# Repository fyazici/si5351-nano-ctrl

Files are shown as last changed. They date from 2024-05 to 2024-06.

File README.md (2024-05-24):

si5351-nano-ctrl
==

This is a simple Arduino Nano project to control the commonly available SI5351 oscillator board (originally from Adafruit). 1.44" SPI TFT/OLED screen is used as the graphical interface. A rotary encoder and 4 buttons allow menu navigation and frequency adjustments.

Features include:
* Full range of frequencies from 2.5 kHz up to 300 MHz (with PLL overclock, performance guaranteed range limited to 225 MHz, see AN619).
* Automatic selection of PLL operation modes based on frequencies requested.
* Adjustable drive strength.
* Up to 6 presets can be saved to EEPROM. Loads `Preset 0` at startup.
* Xtal frequency correction, also stored on EEPROM.

Provided KiCad design is suitable for one-sided PCBs, e.g. made by toner transfer method at home. For two or more layers, PCB design can be optimized to reduce noise and unwanted coupling of SPI signals to the output.

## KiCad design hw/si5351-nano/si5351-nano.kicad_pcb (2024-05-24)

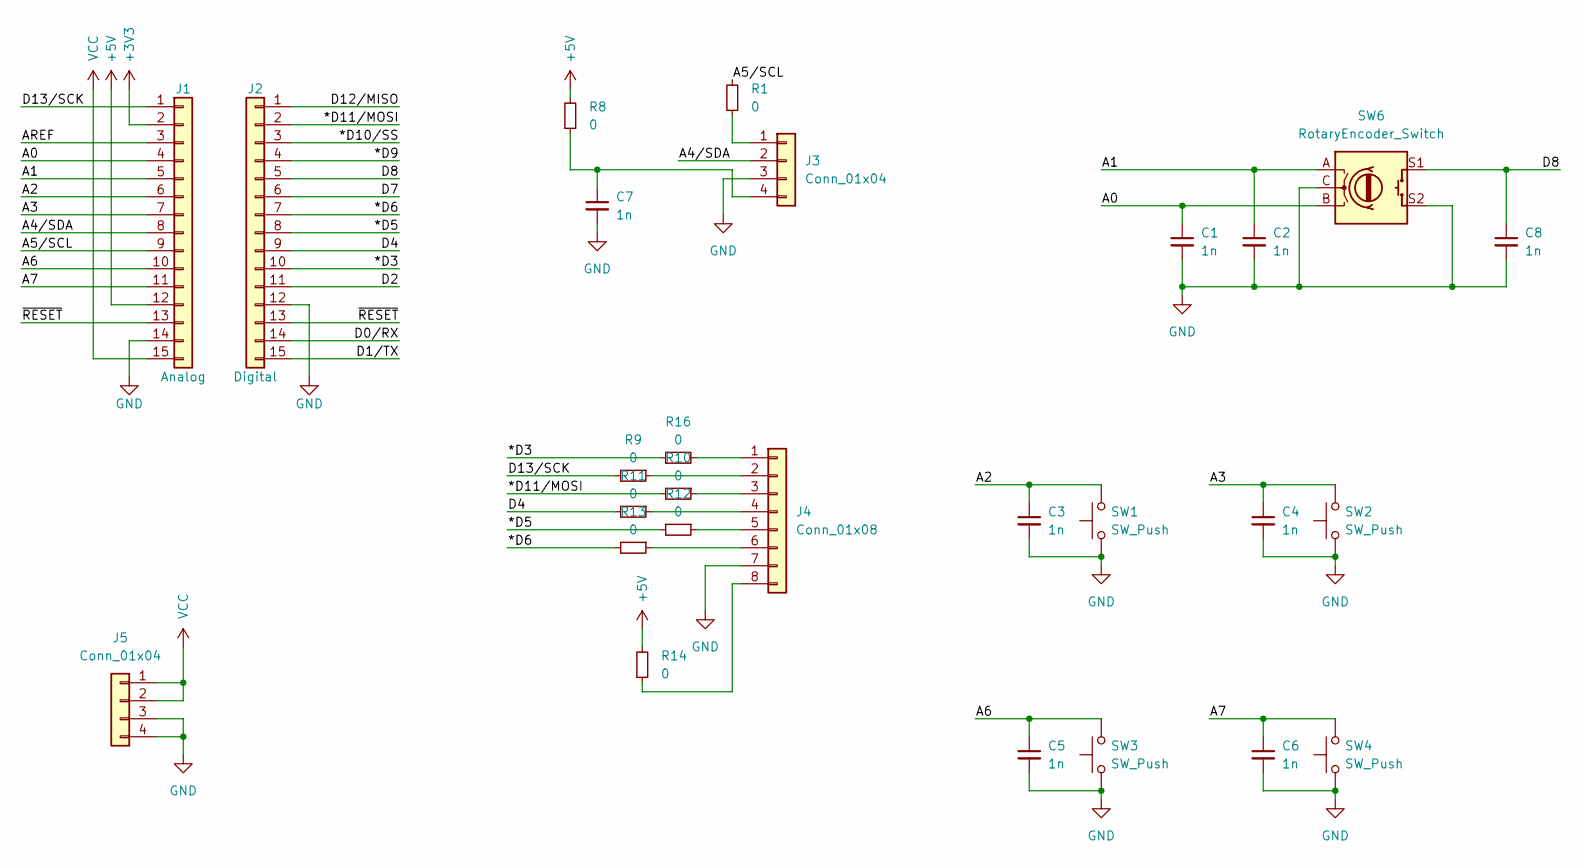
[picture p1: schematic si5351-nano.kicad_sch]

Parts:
C1, C2, C3, C4, C5, C6, C7, C8: 1n; C_1206_3216Metric
J1: Analog; PinHeader_1x15_P2.54mm_Vertical
J2: Digital; PinHeader_1x15_P2.54mm_Vertical
J3, J5: Conn_01x04; PinHeader_1x04_P2.54mm_Vertical
J4: Conn_01x08; PinHeader_1x08_P2.54mm_Vertical
R1, R8, R9, R10, R11, R12, R13, R14, R16: 0; R_1206_3216Metric
SW1, SW2, SW3, SW4: SW_Push; SW_PUSH_6mm
SW6: RotaryEncoder_Switch; RotaryEncoder_Alps_EC11E-Switch_Vertical_H20mm

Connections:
+3V3: J1.2
+5V: J1.12, R8.2, R14.2
/*D3: J2.10, R16.1
/*D5: J2.8, R12.2
/*D6: J2.7, R13.2
/*D9: J2.4
/*D10/SS: J2.3
/*D11/MOSI: J2.2, R10.2
/A0: C1.1, J1.4, SW6.B
/A1: C2.1, J1.5, SW6.A
/A2: C3.1, J1.6, SW1.2
/A3: C4.1, J1.7, SW2.2
/A4/SDA: J1.8, J3.2
/A5/SCL: J1.9, R1.2
/A6: C5.1, J1.10, SW3.2
/A7: C6.1, J1.11, SW4.2
/AREF: J1.3
/D0/RX: J2.14
/D1/TX: J2.15
/D2: J2.11
/D4: J2.9, R11.2
/D7: J2.6
/D8: C8.1, J2.5, SW6.S1
/D12/MISO: J2.1
/D13/SCK: J1.1, R9.2
/~RESET: J1.13, J2.13
GND: C1.2, C2.2, C3.2, C4.2, C5.2, C6.2, C7.2, C8.2, J1.14, J2.12, J3.3, J4.7, J5.3, J5.4, SW1.1, SW2.1, SW3.1, SW4.1, SW6.C, SW6.S2
unnamed: J3.1, R1.1
unnamed: C7.1, J3.4, R8.1
unnamed: J4.1, R16.2
unnamed: J4.2, R9.1
unnamed: J4.3, R10.1
unnamed: J4.4, R11.1
unnamed: J4.5, R12.1
unnamed: J4.6, R13.1
unnamed: J4.8, R14.1
VCC: J1.15, J5.1, J5.2

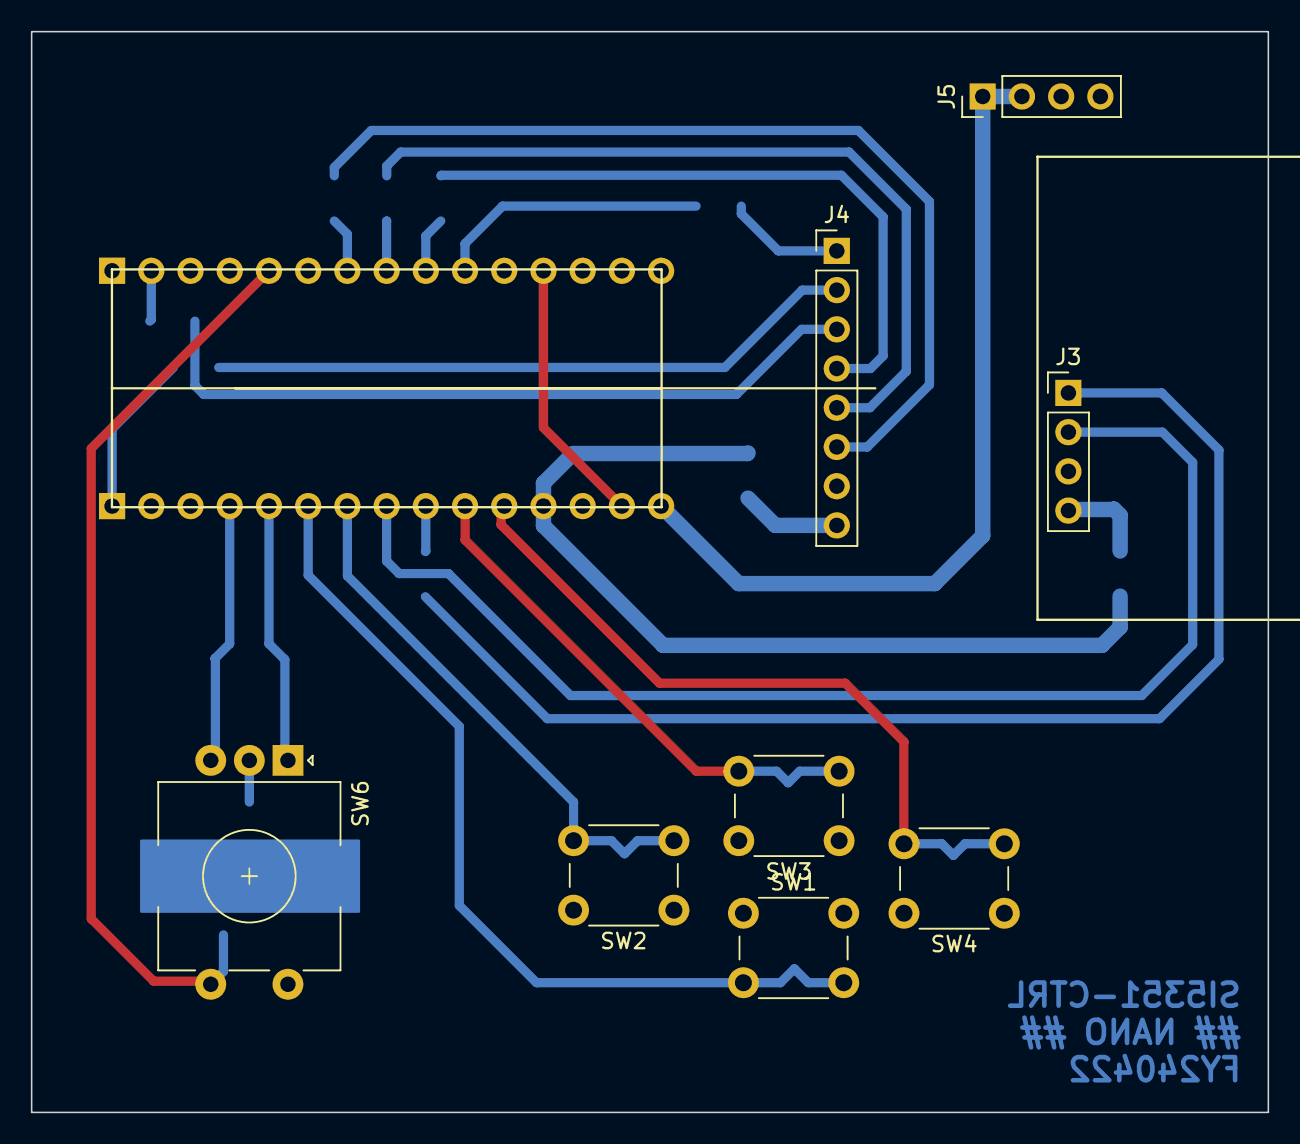
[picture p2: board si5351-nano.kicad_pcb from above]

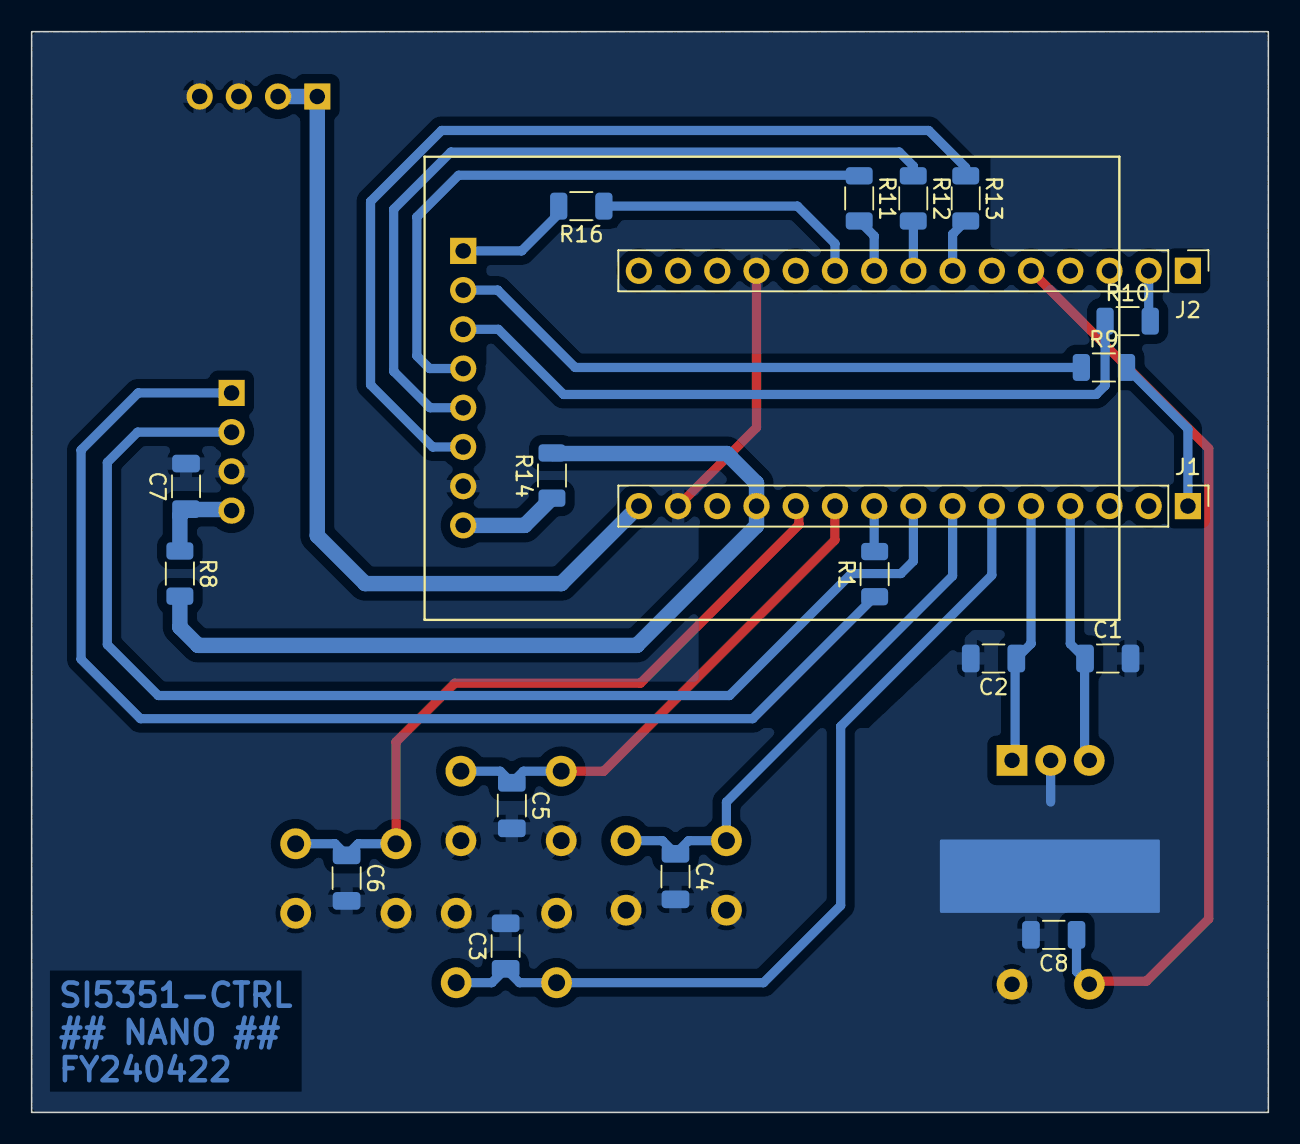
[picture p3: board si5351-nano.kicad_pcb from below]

Board: 2 copper layers, 80.1 x 70.0 mm, 27 parts (19 on the bottom side), 28 nets.

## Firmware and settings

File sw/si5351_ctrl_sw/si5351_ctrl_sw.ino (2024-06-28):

#include <Wire.h>
#include <SPI.h>
#include <EEPROM.h>
#include <Adafruit_GFX.h>     // Core graphics library
#include <Adafruit_ST7735.h>  // Hardware-specific library for ST7735
#include <Fonts/FreeMono9pt7b.h>
#include "SI5351_Ctrl.hpp"
#include "ButtonController.hpp"
#include "RotaryEncoder.hpp"

// cs, dc, rst
Adafruit_ST7735 tft = Adafruit_ST7735(6, 4, 5);

SI5351_Controller clock_ctrl;
ButtonController btn_s(A2), btn_w(A3), btn_n(8), btn_e(7), btn_enc(12);
RotaryEncoder renc(A0, A1);

constexpr int EEPROM_PRESET_BASE = 0;
constexpr int EEPROM_XTAL_CORR_BASE = 124;

constexpr int DISP_BACKLIGHT_PIN = 3;
constexpr uint32_t DISP_TIMEOUT = 60000;

bool disp_redraw;
uint32_t disp_last_activity;

enum class app_state : int {
  SEL_CH = 1,
  ADJ_FREQ = 2,
  PRESET = 3,
  XTAL_CORR = 4,
  APP_INFO = 5
};

#define APP_INFO_STR\
  "SI5351 Controller\n"\
  "w/ Arduino Nano\n\n"\
  "Build:\n"\
  __DATE__ " " __TIME__ "\n"\
  "github.com/fyazici\n/si5351-nano-ctrl"

app_state state;
uint8_t ch_sel, digit_sel, preset_sel;
GFXcanvas1 canvas(128, 32);

void setup() {
  Wire.begin();
  Serial.begin(115200);

  Serial.println(APP_INFO_STR);

  {
    int32_t xtal_freq;
    EEPROM.get(EEPROM_XTAL_CORR_BASE, xtal_freq);
    clock_ctrl.begin(xtal_freq);

    SI5351_Controller::Config cfg;
    int addr = EEPROM_PRESET_BASE;
    EEPROM.get(addr, cfg);
    if (!clock_ctrl.set_config(cfg)) {
      clock_ctrl.set_default();
    }
  }

  // display backlight
  pinMode(DISP_BACKLIGHT_PIN, OUTPUT);
  digitalWrite(DISP_BACKLIGHT_PIN, HIGH);

  tft.initR(INITR_144GREENTAB);
  tft.setRotation(1);
  tft.fillScreen(ST77XX_BLACK);

  canvas.setFont(&FreeMono9pt7b);
  canvas.setTextSize(1);

  btn_s.begin();
  btn_w.begin();
  btn_n.begin();
  btn_e.begin();
  btn_enc.begin();
  renc.begin();

  state = app_state::SEL_CH;
  ch_sel = 0;
  digit_sel = 0;
  preset_sel = 0;

  Serial.print("> ");

  disp_redraw = true;
  disp_last_activity = millis();
}

void print_freq(uint8_t x, uint8_t y, uint32_t freq, int8_t digit_sel) {
  uint8_t xn;
  for (int8_t i = 0; i < 11; i++) {
    xn = x + 11 * (10 - i);
    canvas.setCursor(xn, y + 12);
    if ((freq > 0) && ((i == 3) || (i == 7))) canvas.print("'");
    else {
      if ((freq > 0) || (i == 0)) canvas.print((char)((freq % 10) + 0x30));
      else canvas.print(" ");  // for bg color to show up
      freq /= 10;
    }
  }
  if (digit_sel != -1) {
    if (digit_sel < 3) {
      canvas.fillRect(x + 11 * (10 - digit_sel), y + 14, 11, 2, 1);
    } else if (digit_sel < 6) {
      canvas.fillRect(x + 11 * (9 - digit_sel), y + 14, 11, 2, 1);
    } else {
      canvas.fillRect(x + 11 * (8 - digit_sel), y + 14, 11, 2, 1);
    }
  }
}

void print_freq(uint8_t x, uint8_t y, uint32_t freq) {
  print_freq(x, y, freq, -1);
}

int32_t ipow(int32_t b, int32_t p) {
  int32_t r = 1;
  while (p--) r *= b;
  return r;
}

void fastDraw1(const uint8_t x, const uint8_t y, uint8_t *bitmap, const uint8_t w, const uint8_t h, const uint16_t color, const uint16_t bg) {
  const uint16_t n = w * h / 8;
  uint8_t b;

  tft.startWrite();
  tft.setAddrWindow(x, y, w, h);
  for (uint16_t i = 0; i < n; ++i) {
    b = bitmap[i];
    // unroll for performance
    tft.SPI_WRITE16((b & 0x80) ? color : bg);
    tft.SPI_WRITE16((b & 0x40) ? color : bg);
    tft.SPI_WRITE16((b & 0x20) ? color : bg);
    tft.SPI_WRITE16((b & 0x10) ? color : bg);
    tft.SPI_WRITE16((b & 0x08) ? color : bg);
    tft.SPI_WRITE16((b & 0x04) ? color : bg);
    tft.SPI_WRITE16((b & 0x02) ? color : bg);
    tft.SPI_WRITE16((b & 0x01) ? color : bg);
  }
  tft.endWrite();
}

void ui_draw_ch(uint8_t x, uint8_t y, uint8_t ch, bool selected, uint8_t digit_sel = -1) {
  canvas.fillScreen(0);
  canvas.setFont(&FreeMono9pt7b);

  canvas.setCursor(0, 12);
  canvas.print("C");
  canvas.print(ch);

  canvas.setCursor(36, 12);
  canvas.print(clock_ctrl.get_ch_pll_dsn(ch));
  canvas.print(clock_ctrl.get_ch_pll_mode(ch));

  canvas.setCursor(66, 12);
  canvas.print(clock_ctrl.get_ch_drive_dsn(ch));
  canvas.print("mA ");

  if (clock_ctrl.get_ch_en(ch)) {
    canvas.drawFastHLine(107, 12, 5, 1);
    canvas.drawFastVLine(112, 2, 11, 1);
    canvas.drawFastHLine(112, 2, 5, 1);
    canvas.drawFastVLine(117, 2, 11, 1);
    canvas.drawFastHLine(117, 12, 5, 1);
    canvas.drawFastVLine(122, 2, 11, 1);
    canvas.drawFastHLine(122, 2, 5, 1);
  }
  else {
    canvas.drawFastHLine(107, 7, 20, 1);
  }

  print_freq(6, 14, clock_ctrl.get_ch_freq(ch), digit_sel);

  if (selected) {
    fastDraw1(x, y, canvas.getBuffer(), canvas.width(), canvas.height(), ST77XX_BLACK, ST7735_WHITE);
  } else {
    fastDraw1(x, y, canvas.getBuffer(), canvas.width(), canvas.height(), ST7735_WHITE, ST7735_BLACK);
  }
}

void ui_draw_freq_corr(uint8_t x, uint8_t y, uint8_t digit_sel) {
  canvas.fillScreen(0);
  canvas.setFont(&FreeMono9pt7b);

  canvas.setCursor(0, 12);
  canvas.print("XTAL CORR:");

  print_freq(0, 13, clock_ctrl.get_xtal_freq(), digit_sel);

  fastDraw1(x, y, canvas.getBuffer(), canvas.width(), canvas.height(), ST77XX_WHITE, ST7735_BLUE);
}

void ui_draw_presets(uint8_t x, uint8_t y, uint8_t preset_sel) {
  for (uint8_t i = 0; i < 6; i++) {
    canvas.fillScreen(0);
    canvas.setFont(&FreeMono9pt7b);
    canvas.setCursor(0, 12);
    canvas.print("Preset ");
    canvas.print(i);
    if (i == preset_sel) {
      fastDraw1(x, y + i * 16, canvas.getBuffer(), 128, 16, ST77XX_BLACK, ST7735_WHITE);
    } else {
      fastDraw1(x, y + i * 16, canvas.getBuffer(), 128, 16, ST7735_WHITE, ST7735_BLACK);
    }
  }
}

void ui_draw_info_panel(uint8_t x, uint8_t y) {
  canvas.fillScreen(0);
  // using smaller 8x5 fixed font for bottom info panel
  canvas.setFont();
  canvas.drawFastHLine(0, 0, 128, 1);

  switch (state) {
    case app_state::SEL_CH:
      canvas.setCursor(0, 4);
      canvas.print(" SEL ");
      canvas.setCursor(0, 20);
      canvas.print("(I/O)");
      canvas.drawFastVLine(35, 0, 32, 1);
      canvas.setCursor(65, 2);
      canvas.print("PRESET");
      canvas.setCursor(48, 13);
      canvas.print("-");
      canvas.setCursor(103, 13);
      canvas.print("INFO");
      canvas.setCursor(68, 24);
      canvas.print("ENTER");
      break;
    case app_state::ADJ_FREQ:
      canvas.setCursor(0, 4);
      canvas.print(" ADJ ");
      canvas.setCursor(0, 20);
      canvas.print("(->0)");
      canvas.drawFastVLine(35, 0, 32, 1);
      canvas.setCursor(68, 2);
      canvas.print("DRIVE");
      canvas.setCursor(48, 13);
      canvas.print("<");
      canvas.setCursor(112, 13);
      canvas.print(">");
      canvas.setCursor(71, 24);
      canvas.print("BACK");
      break;
    case app_state::PRESET:
      canvas.setCursor(3, 4);
      canvas.print(" SEL ");
      canvas.setCursor(0, 20);
      canvas.print("(SAVE)");
      canvas.drawFastVLine(35, 0, 32, 1);
      canvas.setCursor(71, 2);
      canvas.print("LOAD");
      canvas.setCursor(48, 13);
      canvas.print("-");
      canvas.setCursor(91, 13);
      canvas.print("DELETE");
      canvas.setCursor(71, 24);
      canvas.print("BACK");
      break;
    case app_state::XTAL_CORR:
      canvas.setCursor(0, 4);
      canvas.print(" ADJ ");
      canvas.setCursor(0, 20);
      canvas.print("(->0)");
      canvas.drawFastVLine(35, 0, 32, 1);
      canvas.setCursor(71, 2);
      canvas.print("SAVE");
      canvas.setCursor(48, 13);
      canvas.setCursor(48, 13);
      canvas.print("<");
      canvas.setCursor(112, 13);
      canvas.print(">");
      canvas.setCursor(71, 24);
      canvas.print("BACK");
      break;
    case app_state::APP_INFO:
      canvas.setCursor(0, 4);
      canvas.print("  -  ");
      canvas.setCursor(0, 20);
      canvas.print("  -  ");
      canvas.drawFastVLine(35, 0, 32, 1);
      canvas.setCursor(80, 2);
      canvas.print("-");
      canvas.setCursor(48, 13);
      canvas.setCursor(48, 13);
      canvas.print("-");
      canvas.setCursor(112, 13);
      canvas.print("-");
      canvas.setCursor(71, 24);
      canvas.print("BACK");
    default:
      break;
  }

  fastDraw1(x, y, canvas.getBuffer(), 128, 32, ST77XX_RED, ST77XX_BLACK);
}

void ui_draw_app_info(uint8_t x, uint8_t y) {
  tft.fillScreen(ST77XX_BLACK);
  tft.setFont();
  tft.setTextColor(ST77XX_GREEN);
  tft.setCursor(x, y);
  tft.print(F(APP_INFO_STR));
}

void process_sel_ch() {
  switch (renc.update()) {
    case RotaryEncoder::Event::CW:
      if (ch_sel == 0) ch_sel = 2;
      else ch_sel--;
      disp_redraw = true;
      break;
    case RotaryEncoder::Event::CCW:
      ch_sel++;
      if (ch_sel > 2) ch_sel = 0;
      disp_redraw = true;
      break;
    default:
      break;
  }
  switch (btn_s.update()) {
    case ButtonController::Event::Click:
      state = app_state::ADJ_FREQ;
      disp_redraw = true;
      break;
    case ButtonController::Event::LongPress:
      state = app_state::PRESET;
      disp_redraw = true;
      break;
    default:
      break;
  }
  switch (btn_n.update()) {
    case ButtonController::Event::Click:
      state = app_state::PRESET;
      disp_redraw = true;
      break;
    default:
      break;
  }
  switch (btn_e.update()) {
    case ButtonController::Event::Click:
      state = app_state::APP_INFO;
      disp_redraw = true;
      break;
    default:
      break;
  }
  switch (btn_enc.update()) {
    case ButtonController::Event::Click:
      clock_ctrl.set_ch_en(ch_sel, !clock_ctrl.get_ch_en(ch_sel));
      disp_redraw = true;
      break;
    case ButtonController::Event::LongPress:
      state = app_state::XTAL_CORR;
      disp_redraw = true;
    default:
      break;
  }
}

void process_adj_freq() {
  int32_t freq = clock_ctrl.get_ch_freq(ch_sel);

  switch (renc.update()) {
    case RotaryEncoder::Event::CW:
      freq += ipow(10, digit_sel);
      freq = min(300000000, freq);
      clock_ctrl.set_ch_freq(ch_sel, freq);
      disp_redraw = true;
      break;
    case RotaryEncoder::Event::CCW:
      freq -= ipow(10, digit_sel);
      freq = max(2500, freq);
      clock_ctrl.set_ch_freq(ch_sel, freq);
      disp_redraw = true;
      break;
    default:
      break;
  }
  switch (btn_enc.update()) {
    case ButtonController::Event::Click:
      freq = (freq / ipow(10, digit_sel + 1)) * ipow(10, digit_sel + 1);
      freq = min(300000000, max(2500, freq));
      clock_ctrl.set_ch_freq(ch_sel, freq);
      disp_redraw = true;
      break;
    default:
      break;
  }
  switch (btn_s.update()) {
    case ButtonController::Event::Click:
      state = app_state::SEL_CH;
      disp_redraw = true;
      break;
    default:
      break;
  }
  switch (btn_e.update()) {
    case ButtonController::Event::Click:
      {
        if (digit_sel == 0) digit_sel = 8;
        else digit_sel--;
        disp_redraw = true;
        break;
      }
    default:
      break;
  }
  switch (btn_w.update()) {
    case ButtonController::Event::Click:
      {
        digit_sel++;
        if (digit_sel > 8) digit_sel = 0;
        disp_redraw = true;
        break;
      }
    default:
      break;
  }
  switch (btn_n.update()) {
    case ButtonController::Event::Click:
      {
        auto mode = clock_ctrl.get_ch_drive_strength(ch_sel);
        mode = (mode + 1) % 4;
        clock_ctrl.set_ch_drive_strength(ch_sel, mode);
        disp_redraw = true;
      }
      break;
    default:
      break;
  }
}

void process_preset() {
  switch (renc.update()) {
    case RotaryEncoder::Event::CW:
      if (preset_sel == 0) preset_sel = 5;
      else preset_sel--;
      disp_redraw = true;
      break;
    case RotaryEncoder::Event::CCW:
      preset_sel++;
      if (preset_sel > 5) preset_sel = 0;
      disp_redraw = true;
      break;
    default:
      break;
  }
  switch (btn_s.update()) {
    case ButtonController::Event::Click:
      state = app_state::SEL_CH;
      disp_redraw = true;
      break;
    default:
      break;
  }
  switch (btn_e.update()) {
    case ButtonController::Event::Click:
      {
        Serial.println("I: delete preset");
        SI5351_Controller::Config cfg;
        int addr = EEPROM_PRESET_BASE + preset_sel * sizeof(cfg);
        EEPROM.get(addr, cfg);
        cfg.checksum ^= 0xFF; // inverting checksum invalidates entry
        EEPROM.put(addr, cfg);
      }
      state = app_state::SEL_CH;
      disp_redraw = true;
      break;
    default:
      break;
  }
  switch (btn_enc.update()) {
    case ButtonController::Event::Click:
      {
        Serial.println("I: save preset");
        auto cfg = clock_ctrl.get_config();
        cfg.dump();
        int addr = EEPROM_PRESET_BASE + preset_sel * sizeof(cfg);
        EEPROM.put(addr, cfg);
        state = app_state::SEL_CH;
        disp_redraw = true;
      }
      break;
    default:
      break;
  }
  switch (btn_n.update()) {
    case ButtonController::Event::Click:
      {
        Serial.println("I: load preset");
        SI5351_Controller::Config cfg;
        int addr = EEPROM_PRESET_BASE + preset_sel * sizeof(cfg);
        EEPROM.get(addr, cfg);
        cfg.dump();
        clock_ctrl.set_config(cfg);
        state = app_state::SEL_CH;
        disp_redraw = true;
      }
      break;
    default:
      break;
  }
}

void process_xtal_corr() {
  int32_t freq = clock_ctrl.get_xtal_freq();

  switch (renc.update()) {
    case RotaryEncoder::Event::CW:
      freq += ipow(10, digit_sel);
      freq = min(30000000, freq);
      clock_ctrl.set_xtal_freq(freq);
      disp_redraw = true;
      break;
    case RotaryEncoder::Event::CCW:
      freq -= ipow(10, digit_sel);
      freq = max(20000000, freq);
      clock_ctrl.set_xtal_freq(freq);
      disp_redraw = true;
      break;
    default:
      break;
  }
  switch (btn_enc.update()) {
    case ButtonController::Event::Click:
      freq = (freq / ipow(10, digit_sel + 1)) * ipow(10, digit_sel + 1);
      clock_ctrl.set_xtal_freq(freq);
      disp_redraw = true;
      break;
    default:
      break;
  }
  switch (btn_s.update()) {
    case ButtonController::Event::Click:
      state = app_state::SEL_CH;
      disp_redraw = true;
      break;
    default:
      break;
  }
  switch (btn_e.update()) {
    case ButtonController::Event::Click:
      if (digit_sel == 0) digit_sel = 8;
      else digit_sel--;
      disp_redraw = true;
      break;
    default:
      break;
  }
  switch (btn_w.update()) {
    case ButtonController::Event::Click:
      digit_sel++;
      if (digit_sel > 8) digit_sel = 0;
      disp_redraw = true;
      break;
    default:
      break;
  }
  switch (btn_n.update()) {
    case ButtonController::Event::Click:
      Serial.println("I: save xtal correction");
      EEPROM.put(EEPROM_XTAL_CORR_BASE, freq);
      state = app_state::SEL_CH;
      disp_redraw = true;
      break;
    default:
      break;
  }
}

void process_app_info() {
  switch (btn_s.update()) {
    case ButtonController::Event::Click:
      state = app_state::SEL_CH;
      disp_redraw = true;
      break;
    default:
      break;
  }
}


void process_shell() {
  static char buffer[8] = { 0 };
  static uint8_t idx = 0;
  
  char cmd;
  uint8_t addr, val;
  bool e = false;
  
  if (Serial.available()) {
    char c = (char)Serial.read();
    Serial.write(c);
    if (c == '\n') {
      buffer[idx] = 0;
      idx = 0;

      if (sscanf(buffer, " %c %hhu %hhx", &cmd, &addr, &val) == 3) {
        switch (cmd) {
          case 'w':
          case 'W':
            clock_ctrl.__raw_write_reg(addr, val);
            break;
          case 'r':
          case 'R':
            val = clock_ctrl.__raw_read_reg(addr);
            Serial.println(val, HEX);
            break;
          default:
            e = true;
            break;
        }
        Serial.flush();
        Serial.print("> ");
      } else {
        e = true;
      }
      if (e) {
        Serial.print(F("usage: \nw A V : reg(A)<=V\nr A 0 : V<=r(A)\n"));
        Serial.print("\n> ");
      }
    } else {
      if (idx < sizeof(buffer)) {
        buffer[idx++] = c;
      } else {
        Serial.flush();
        idx = 0;
        Serial.println(F("E: shell buffer overrun (8)"));
        Serial.print("\n> ");
      }
    }
  }
}

void loop() {

  auto t = millis();

  process_shell();

  switch (state) {
    case app_state::SEL_CH:
      process_sel_ch();
      break;
    case app_state::ADJ_FREQ:
      process_adj_freq();
      break;
    case app_state::PRESET:
      process_preset();
      break;
    case app_state::XTAL_CORR:
      process_xtal_corr();
      break;
    case app_state::APP_INFO:
      process_app_info();
      break;
    default:
      break;
  }

  if (disp_redraw) {
    tft.enableDisplay(true);
    delay(50);
    digitalWrite(DISP_BACKLIGHT_PIN, HIGH);

    disp_last_activity = millis();
    switch (state) {
      case app_state::SEL_CH:
        ui_draw_ch(0, 0, 0, ch_sel == 0);
        ui_draw_ch(0, 32, 1, ch_sel == 1);
        ui_draw_ch(0, 64, 2, ch_sel == 2);
        break;
      case app_state::ADJ_FREQ:
        if (ch_sel == 0) ui_draw_ch(0, 0, 0, true, digit_sel);
        else tft.fillRect(0, 0, 128, 32, ST77XX_BLACK);
        if (ch_sel == 1) ui_draw_ch(0, 32, 1, true, digit_sel);
        else tft.fillRect(0, 32, 128, 32, ST77XX_BLACK);
        if (ch_sel == 2) ui_draw_ch(0, 64, 2, true, digit_sel);
        else tft.fillRect(0, 64, 128, 32, ST77XX_BLACK);
        break;
      case app_state::PRESET:
        ui_draw_presets(0, 0, preset_sel);
        break;
      case app_state::XTAL_CORR:
        ui_draw_freq_corr(0, 0, digit_sel);
        tft.fillRect(0, 32, 128, 96, ST77XX_BLACK);
        break;
      case app_state::APP_INFO:
        ui_draw_app_info(0, 0);
        break;
      default:
        break;
    }
    ui_draw_info_panel(0, 96);
    disp_redraw = false;
  } else {
    delay(33);
  }

  if ((millis() - disp_last_activity) > DISP_TIMEOUT) {
    digitalWrite(DISP_BACKLIGHT_PIN, LOW);
    tft.enableDisplay(false);
    state = app_state::SEL_CH;
  }
}

// NOTE: change PCINT0-2 based on pins used for encoder output A
ISR(PCINT1_vect) {
  renc.callback();
}

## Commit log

2024-05-25 fixed drive strength issue. added info screen.
    [si5351_ctrl_sw.ino]
2024-05-26 set output powerdown when not enabled.
2024-06-28 added simple shell for reg access. display timeout. preset load bug fix. debug cleanup. removed build outputs.
    [si5351_ctrl_sw.ino]
